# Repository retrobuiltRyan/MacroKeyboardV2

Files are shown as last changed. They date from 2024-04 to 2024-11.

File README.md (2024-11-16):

# MacroKeyboardV2
13-Key Arduino ProMicro USB Macro Keyboard
https://youtu.be/IDlcxLQ1SbY?si=J5Tzyvr0lGsu_4_Y

cache_4109089450

Trouble Shooting Tips and FAQs
Some basic trouble shooting:

 1. This PCB is not plug-and-play. You have to upload at least the example code linked from this product description. Code is on this page.
 2. Use the Arduino IDE to program. (see arduino.cc for help with adding libraries and getting the software to program the Arduino).
 3. Make sure you have these libraries added:
 4. Make sure the Arduino Micro 32u4 is selected when programming this board. Tools> Board> Arduino Micro.
 cache_4108825371

Go to Tools>Manage Libraries.

cache_4108825370

2) Make sure you have the Arduino Pro Micro selected. Tools> Board> Arduino Micro

5. Make sure all the solder jumpers are soldered! You’ll get really weird results (phantom keys) if you miss a jumper.

6. You may have to hold down the reset button, hit upload sketch, wait for the IDE to try to ‘upload’ to the Arduino, then release the reset button.
The boot-loader for uploading is a short window in the Arduino Pro Micro. The Pro Micro wants to default to the USB HID mode. Catching the short window for uploading a program might take a few tries; i.e to get a feel for the timing (my experience).
Search for these libraries. When you find the library listed below, install it.
7. DO NOT SOLDER BOTH I2C power jumpers. Solder only one!
8. cache_4109097346

Eagle CAD files include (9.2.x) I have abondoned EagleCAD for KiCAD. KiCAD can import Eagle design files; happy macro-ing!eagle work

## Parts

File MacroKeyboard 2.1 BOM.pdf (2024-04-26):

Macro Keyboard ver 2.x Bill of Materials | RetroBuiltGames.com (c) Ryan Bates

### Dec 24, 2020

PRO MODEL | FULL RGB Typical Build
Index | Quantity Description | Vendor | Vendor Part Number | Unit Price Extended Price USD | Notes
1 | 1 | Arduino Pro Micro (micro USB conn) ATmega32u4 | - | - | 3.75 | 3.75
2 | 1 | MacroKeyboard v2.x PCB | Ryan | - | 5.00 | 5.00
3 | 11 | Cherry Mx Switch, Blue, RGB SPST-NO | - | - | 0.95 | 10.43 | 3
4 | 11 | CHERRY MX KEYCAP - Clear or Windowed | - | - | 0.95 | 10.45
5 | 2 | Rotary Encoder w/ Switch | DigiKey | 987-1398-ND | 0.78 | 1.56
6 | 2 | Knob for Rotary shaft, 6mm dia | ebay | - | 0.65 | 1.30
7 | 1 | CONN JACK STEREO 3.5MM R/A | DigiKey | CP1-3524NG-ND (or CP1-3523N-ND) | 0.74 | 0.74
8 | 1 | SWITCH TACTILE SPST-NO 0.05A 12V (6x6mm) | DigiKey | 679-2443-ND | 0.30 | 0.30
9 | 0 | CAP KEYSWITCH SQUARE BLACK for 6x6mm switch (OPTIONAL) | DigiKey | 450-1829-ND | 0.12 | -
10 | 2 | 1x12 Header 0.1" pitch | DigiKey | S6100-ND | 0.69 | 1.38
11 | 0 | Diode, small signal. SOD-123 (OPTIONAL) | DigiKey | 1N4148W-13FDICT-ND | 0.18 | - | 1
12 | 1 | RES 330 OHM 5% 1/4W 1206 | DigiKey | RMCF1206JT330RCT-ND | 0.03 | 0.03
13 | 13 | SK6812 MINI-E Addressable RGB LED 5V | AliExpress | https://www.aliexpress.com/item/4000475685852.html?spm=a2g0s.12269583.0.0.572c1e9ceHD99V 0.50 | | 6.50 | 2
14 | 1 | 3D Printed Case - Custom- | Ryan? | - | 0.48 | 0.48
15 | 1 | LCD 4x20 with i2c backpack (or any i2c LCD) | - | - | 4.00 | 4.00
16 | 1 | Potentiometer 5K Ohm (the big kind, like a volume knob) | ebay | - | 1.00 | 1.00
17 | 1 | Screw Terminal, 3 Pos, 5mm pitch | ebay | - | 0.75 | 0.75
| | | total cost | | | 47.67

As Cheap as Possible, No Keyboard switches
Index | Quantity Description | Vendor | Vendor Part Number | Unit Price Extended Price USD | Notes
1 | 1 | Arduino Pro Micro (micro USB conn) ATmega32u4 | - | - | 3.75 | 3.75
2 | 1 | MacroKeyboard v2.x PCB | Ryan | - | 5.00 | 5.00
3 | 11 | SWITCH TACTILE SPST-NO 0.05A 24V (12x12mm) | DigiKey | 450-1158-ND | 0.33 | 3.63 | 4
4 | 11 | CAP TACTILE ROUND BLACK | DigiKey | 679-2315-ND | 0.21 | 2.31
5 | 2 | Rotary Encoder w/ Switch | DigiKey | 987-1398-ND | 0.78 | 1.56
6 | 2 | Knob for Rotary shaft, 6mm dia | ebay | - | 0.65 | 1.30
7 | 0 | CONN JACK STEREO 3.5MM R/A | DigiKey | CP1-3524NG-ND (or CP1-3523N-ND) | 0.74 | -
8 | 1 | SWITCH TACTILE SPST-NO 0.05A 12V (6x6mm) | DigiKey | 679-2443-ND | 0.30 | 0.30
9 | 0 | CAP KEYSWITCH SQUARE BLACK for 6x6mm switch (OPTIONAL) | DigiKey | 450-1829-ND | 0.12 | -
10 | 0 | 1x12 Header 0.1" pitch | DigiKey | S6100-ND | 0.69 | -
11 | 0 | Diode, small signal. SOD-123 (OPTIONAL) | DigiKey | 1N4148W-13FDICT-ND | 0.18 | - | 1
12 | 0 | RES 330 OHM 5% 1/4W 1206 | DigiKey | RMCF1206JT330RCT-ND | 0.03 | -
13 | 0 | SK6812 MINI-E Addressable RGB LED 5V | AliExpress | https://www.aliexpress.com/item/4000475685852.html?spm=a2g0s.12269583.0.0.572c1e9ceHD99V 0.50 | | - | 2
14 | 0 | 3D Printed Case - Custom- | Ryan? | | 0.48 | -
15 | 0 | Potentiometer 5K Ohm (the big kind, like a volume knob) | ebay | - | 1.00 | -
16 | 0 | Screw Terminal, 3 Pos, 5mm pitch | ebay | - | 0.75 | -
17 | 0 | LCD 4x20 with i2c backpack (or any i2c LCD) | - | - | 4.00 | -
| | | total cost | | | 17.85

Notes:
1 Optional; solder bypass jumper pads if not using anti-ghosting diodes.
2 Haven't found a reliable supplier for this part. Check datasheet before buying!
3 Any compatible keyboard switch will work. Can sub for non- transparent body if not backlighting with LEDs 4 Use generic tac switch, not Omrom (locating holes arent drilled for the Omrom nubs)

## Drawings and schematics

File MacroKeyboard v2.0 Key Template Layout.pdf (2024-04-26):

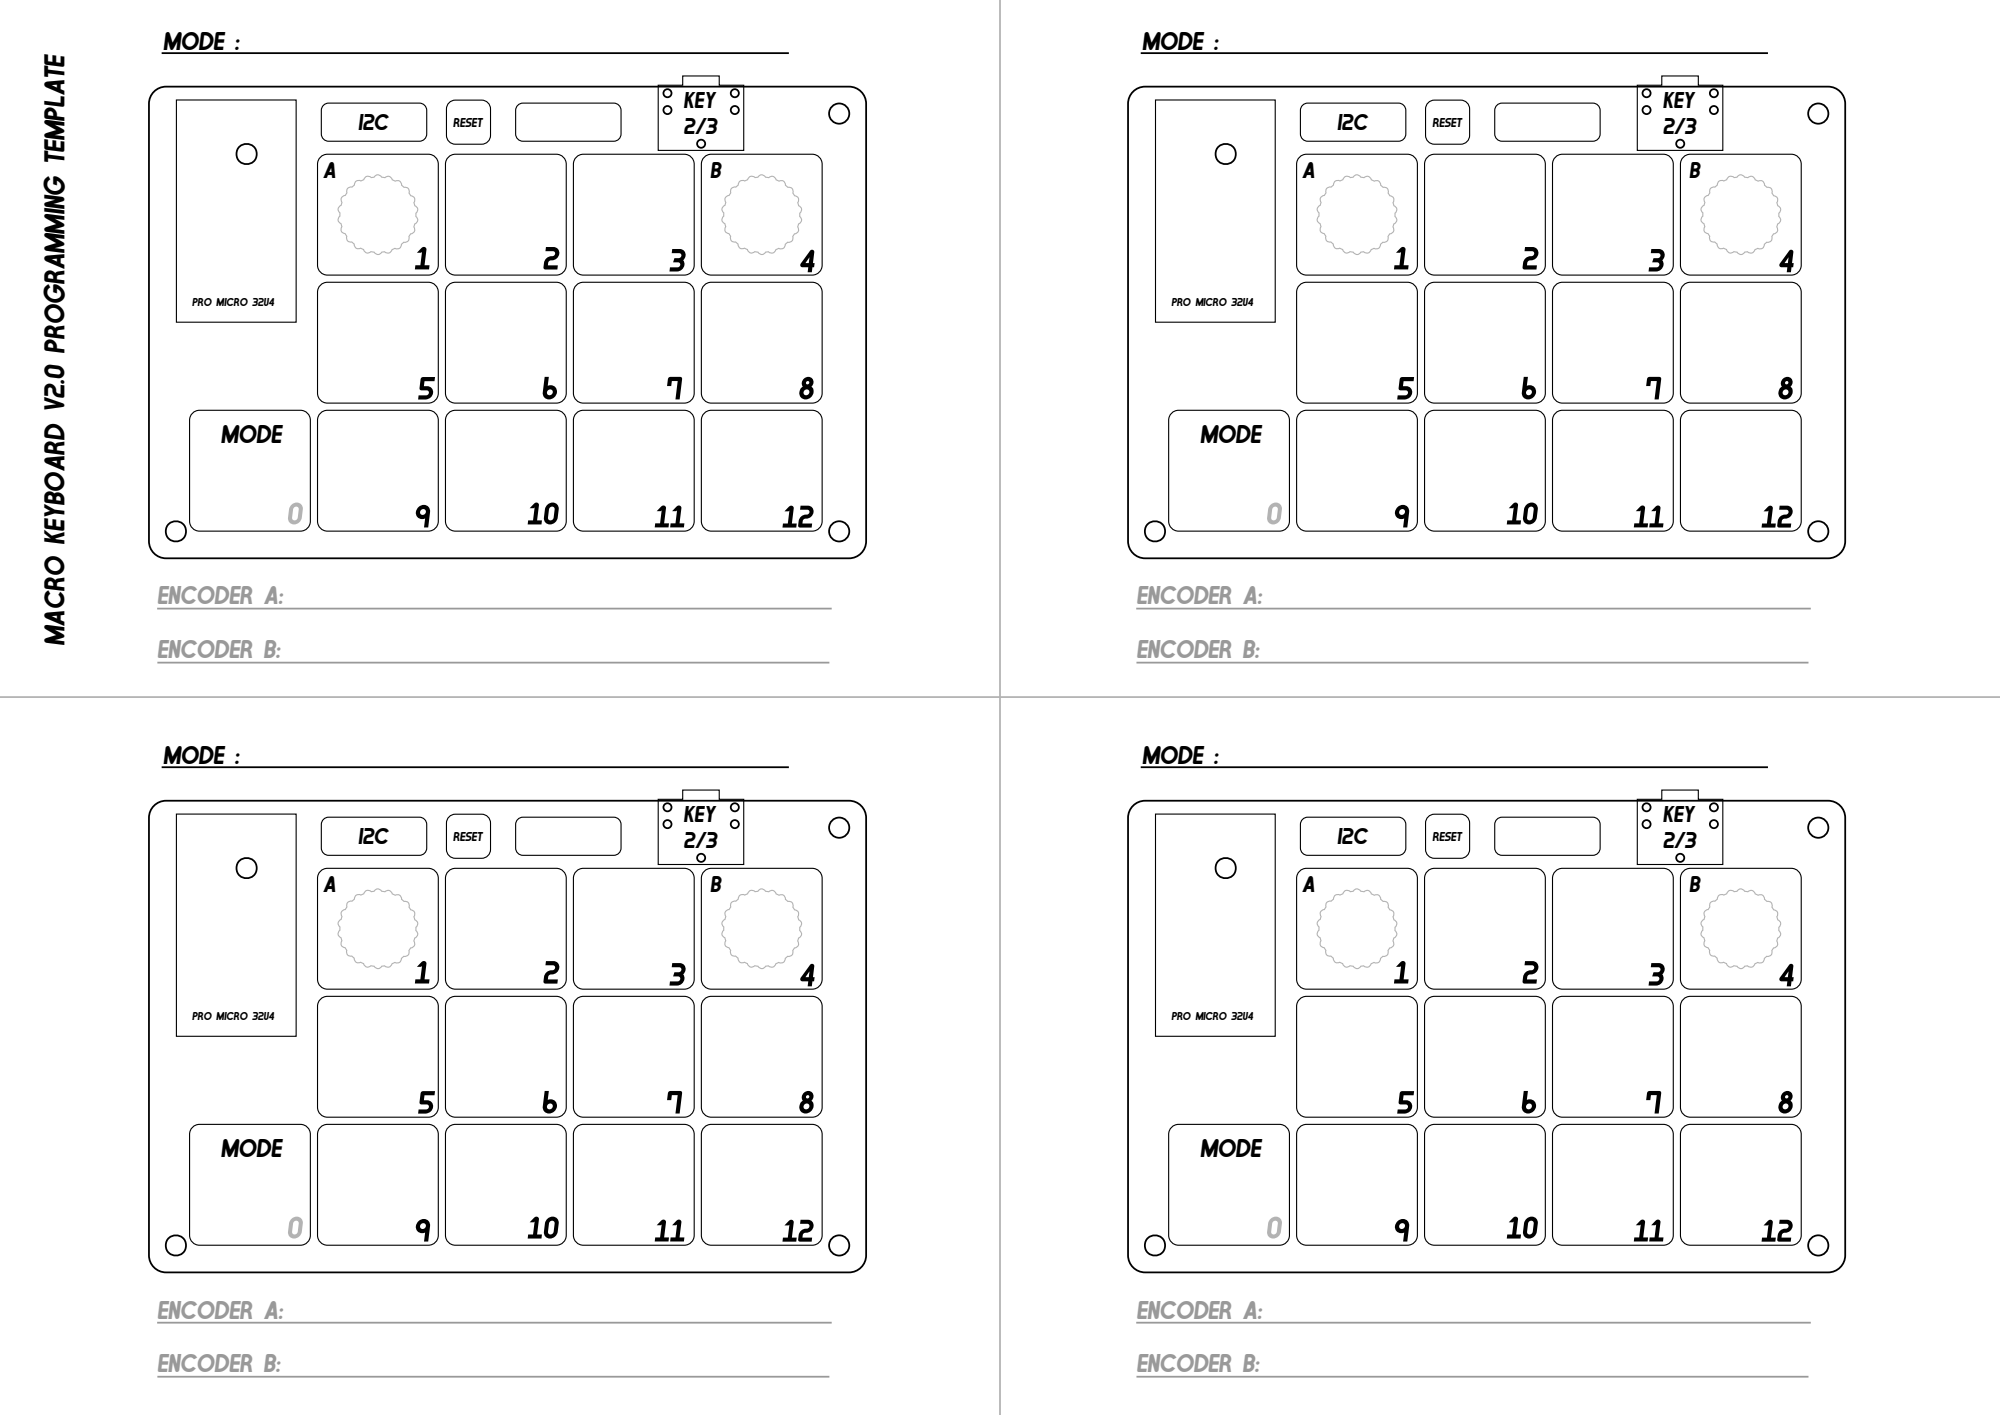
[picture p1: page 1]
PRO MICRO 32U4; RESET; MODE; KEY 2/3; MODE :; ENCODER A:; ENCODER B:

MACRO KEYBOARD V2.0 PROGRAMMING TEMPLATE

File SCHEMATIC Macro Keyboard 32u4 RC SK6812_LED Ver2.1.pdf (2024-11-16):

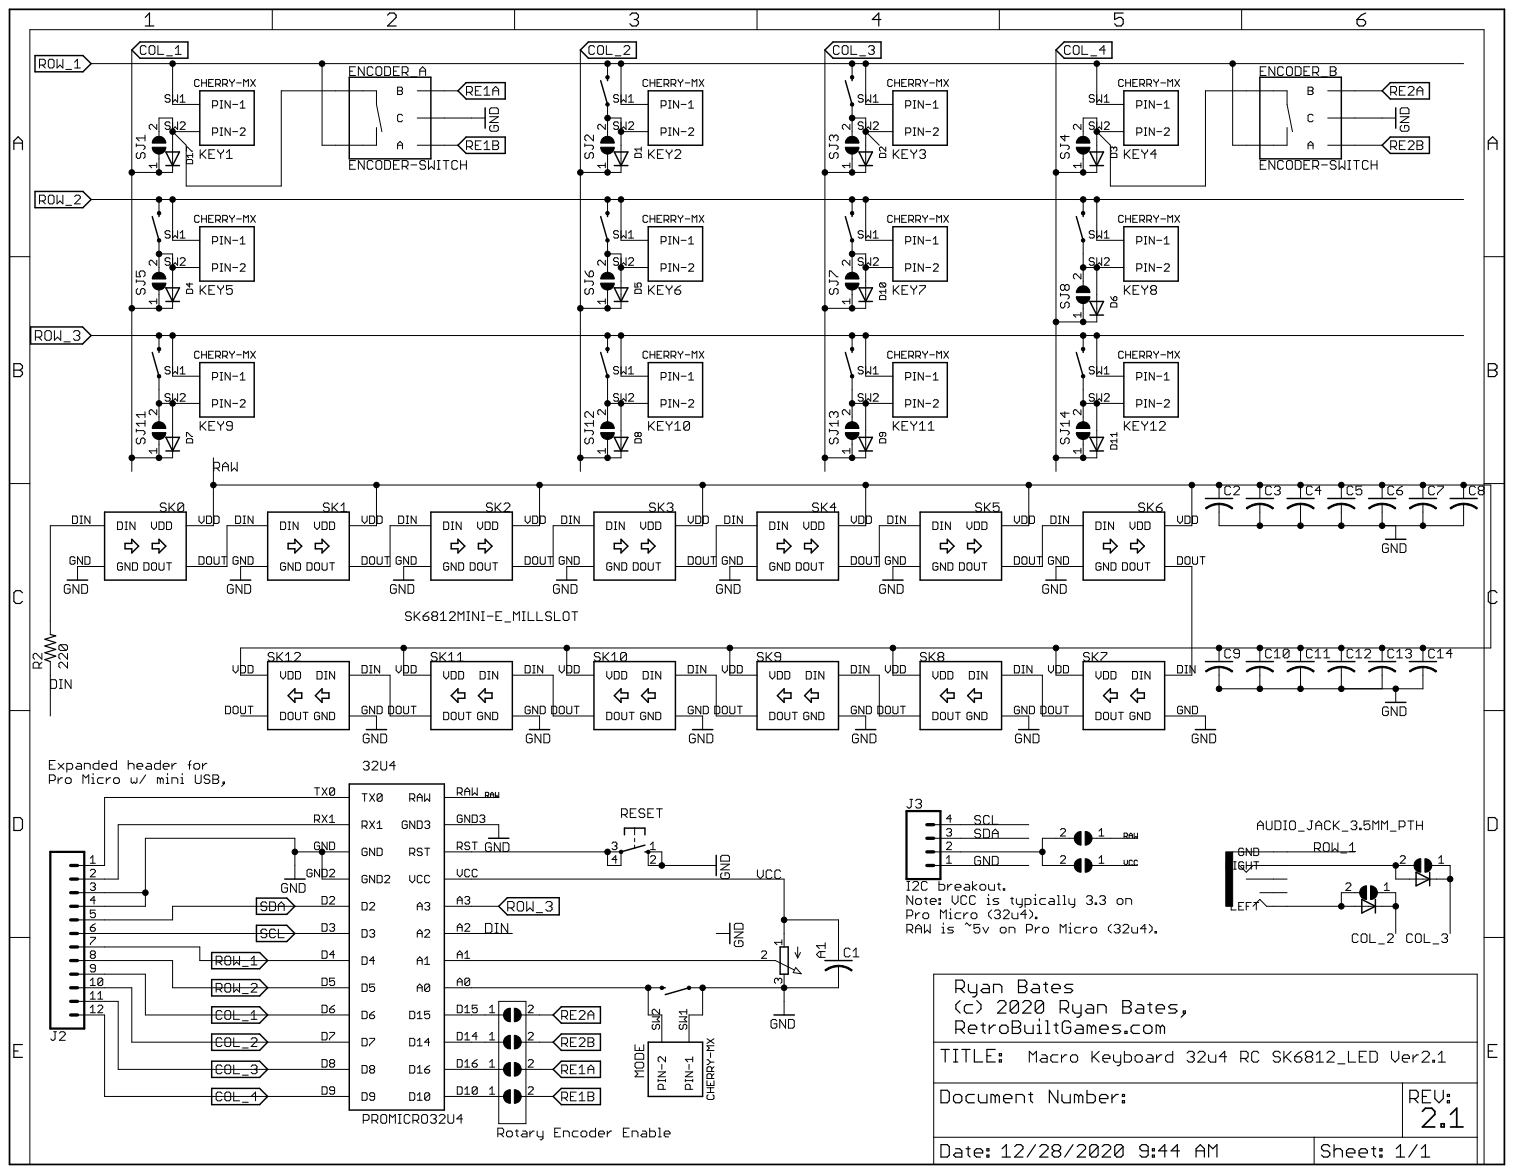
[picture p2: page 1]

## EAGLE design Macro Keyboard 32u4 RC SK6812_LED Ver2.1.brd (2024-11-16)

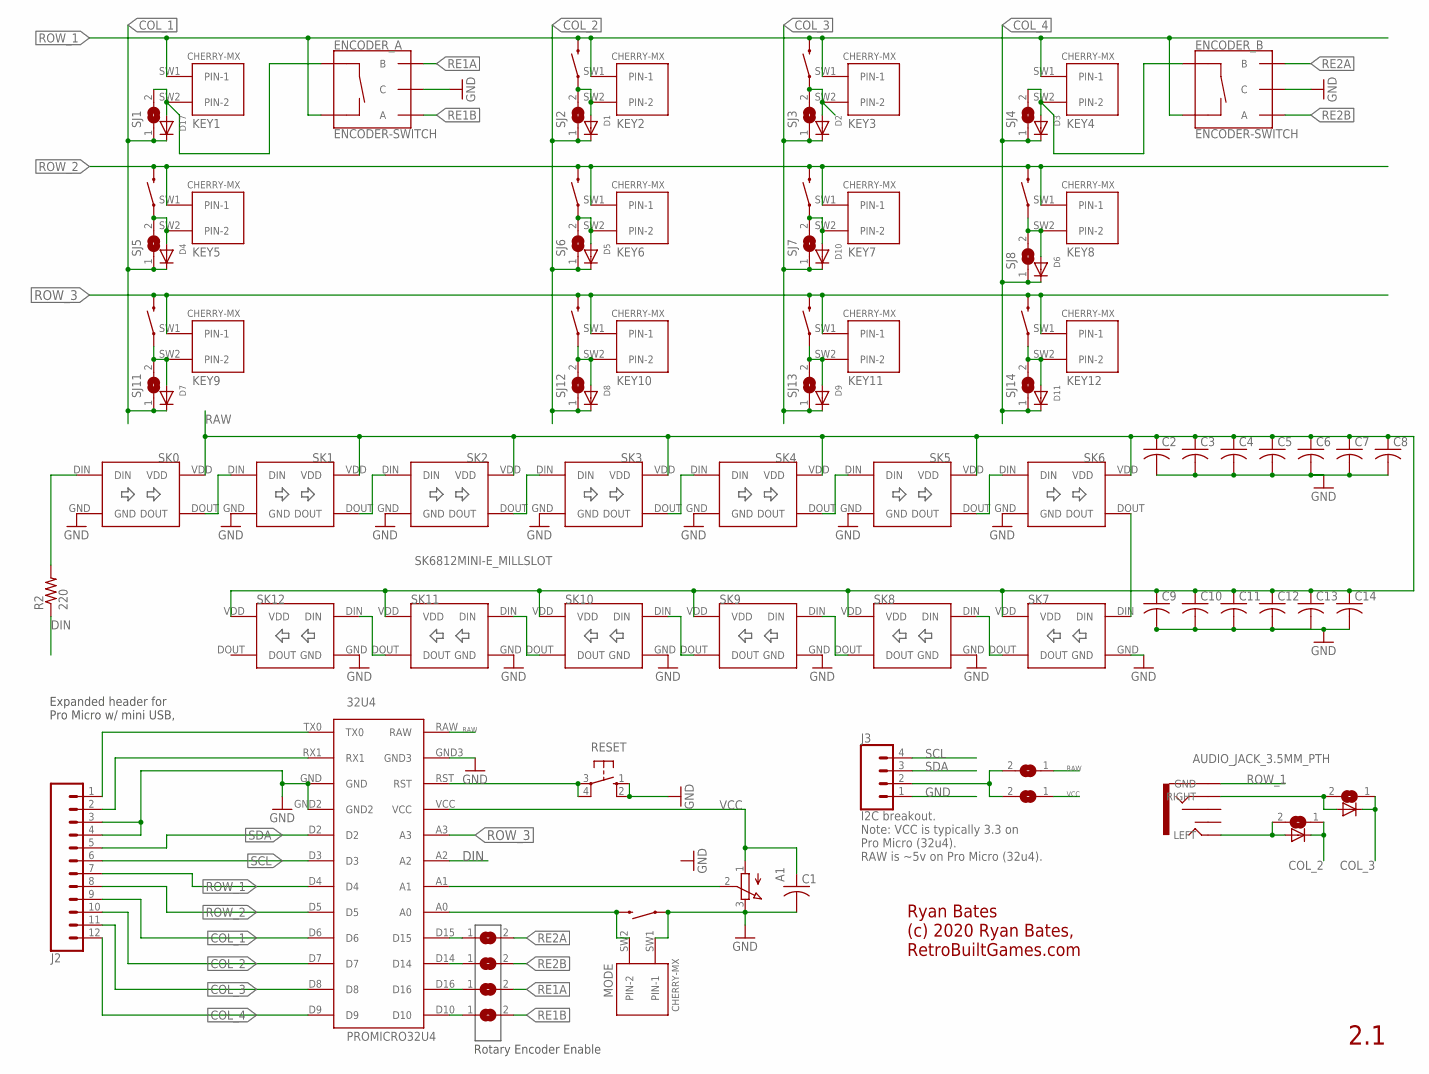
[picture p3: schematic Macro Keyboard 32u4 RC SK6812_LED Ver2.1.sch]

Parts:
32U4: PROMICRO32U4
A1: 3RP/1610N
C1: C-USC1206; C1206
C2, C3, C4, C5, C6, C7, C8, C9, C10, C11, C12, C13, C14: C-USC0805K; C0805K
D1, D2, D3, D4, D5, D6, D7, D8, D9, D10, D11, D15, D16, D17: DIODESOD-123; SOD-123
ENCODER_A: ENCODER-SWITCH; ROTARY_ENC_PLAIN
ENCODER_B: ENCODER-SWITCH; ROTARY_ENC_PLAIN
J1: AUDIO_JACK_3.5MM_PTH; AUDIO-JACK
J2: CONN_12NO_SILK; 1X12_NO_SILK
J3: CONN_041X04_NO_SILK; 1X04_NO_SILK
KEY1, KEY2, KEY3, KEY4, KEY5, KEY6, KEY7, KEY8, KEY9, KEY10, KEY11, KEY12: CHERRY-MX
MODE: CHERRY-MX
R2: 220; M1206
RESET: 10-XX; B3F-10XX
S1, S2, S3, S4, S5, S6, S7, S8, S9, S10, S11: MOMENTARY-SWITCH-SPST-PTH-12MM; TACTILE_SWITCH_PTH_12MM
SJ1, SJ2, SJ3, SJ4, SJ5, SJ6, SJ7, SJ8, SJ9, SJ10, SJ11, SJ12, SJ13, SJ14, SJ16, SJ17, SJ18, SJ19, SJ20, SJ21: SJ
SK0, SK1, SK2, SK3, SK4, SK5, SK6, SK7, SK8, SK9, SK10, SK11, SK12: SK6812MINI-E_MILLSLOT

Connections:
COL_1: 32U4.D6, D4.C, D7.C, D17.C, J2.9, SJ1.1, SJ5.1, SJ11.1
COL_2: 32U4.D7, D1.C, D5.C, D8.C, D15.C, J2.10, SJ2.1, SJ6.1, SJ12.1, SJ16.1
COL_3: 32U4.D8, D2.C, D9.C, D10.C, D16.C, J2.11, SJ3.1, SJ7.1, SJ13.1, SJ17.1
COL_4: 32U4.D9, D3.C, D6.C, D11.C, J2.12, SJ4.1, SJ8.1, SJ14.1
DIN: 32U4.A2, R2.1
GND: 32U4.GND, 32U4.GND2, 32U4.GND3, A1.3 (E), C1.2, C2.2, C3.2, C4.2, C5.2, C6.2, C7.2, C8.2, C9.2, C10.2, C11.2, C12.2, C13.2, C14.2, ENCODER_A.C, ENCODER_B.C, J2.3, J2.4, J3.1, MODE.SW1 (PIN-1), RESET.1 (S), RESET.2 (S1), S11.1, SK0.GND, SK1.GND, SK2.GND, SK3.GND, SK4.GND, SK5.GND, SK6.GND, SK7.GND, SK8.GND, SK9.GND, SK10.GND, SK11.GND, SK12.GND
unnamed: 32U4.RX1, J2.2
unnamed: D1.A, KEY2.SW2 (PIN-2), S4.1, SJ2.2
unnamed: D4.A, KEY5.SW2 (PIN-2), S9.1, SJ5.2
unnamed: D5.A, KEY6.SW2 (PIN-2), S10.1, SJ6.2
unnamed: SK0.DOUT, SK1.DIN
unnamed: D3.A, ENCODER_B.SW+, KEY4.SW2 (PIN-2), SJ4.2
unnamed: D2.A, KEY3.SW2 (PIN-2), S3.1, SJ3.2
unnamed: D16.A, J1.RIGHT, SJ17.2
unnamed: 32U4.RST, RESET.3, RESET.4 (P1)
unnamed: 32U4.TX0, J2.1
unnamed: 32U4.A0, MODE.SW2 (PIN-2), S11.3 (2)
unnamed: SK1.DOUT, SK2.DIN
unnamed: SK2.DOUT, SK3.DIN
unnamed: D10.A, KEY7.SW2 (PIN-2), S1.1, SJ7.2
unnamed: R2.2, SK0.DIN
unnamed: D6.A, KEY8.SW2 (PIN-2), S2.1, SJ8.2
unnamed: D17.A, ENCODER_A.SW+, KEY1.SW2 (PIN-2), SJ1.2
unnamed: SK3.DOUT, SK4.DIN
unnamed: J3.2, SJ9.2, SJ10.2
unnamed: D7.A, KEY9.SW2 (PIN-2), S5.1, SJ11.2
unnamed: 32U4.A1, A1.2 (S)
unnamed: D9.A, KEY11.SW2 (PIN-2), S7.1, SJ13.2
unnamed: D8.A, KEY10.SW2 (PIN-2), S6.1, SJ12.2
unnamed: D11.A, KEY12.SW2 (PIN-2), S8.1, SJ14.2
unnamed: SK4.DOUT, SK5.DIN
unnamed: SK5.DOUT, SK6.DIN
unnamed: SK6.DOUT, SK7.DIN
unnamed: SK7.DOUT, SK8.DIN
unnamed: SK8.DOUT, SK9.DIN
unnamed: SK9.DOUT, SK10.DIN
unnamed: 32U4.D15, SJ18.1
unnamed: 32U4.D14, SJ19.1
unnamed: 32U4.D16, SJ20.1
unnamed: 32U4.D10, SJ21.1
unnamed: SK10.DOUT, SK11.DIN
unnamed: SK11.DOUT, SK12.DIN
unnamed: D15.A, J1.LEFT, SJ16.2
RAW: 32U4.RAW, C2.1, C3.1, C4.1, C5.1, C6.1, C7.1, C8.1, C9.1, C10.1, C11.1, C12.1, C13.1, C14.1, SJ9.1, SK0.VDD, SK1.VDD, SK2.VDD, SK3.VDD, SK4.VDD, SK5.VDD, SK6.VDD, SK7.VDD, SK8.VDD, SK9.VDD, SK10.VDD, SK11.VDD, SK12.VDD
RE1A: ENCODER_A.B, SJ20.2
RE1B: ENCODER_A.A, SJ21.2
RE2A: ENCODER_B.B, SJ18.2
RE2B: ENCODER_B.A, SJ19.2
ROW_1: 32U4.D4, ENCODER_A.SW-, ENCODER_B.SW-, J1.GND, J2.7, KEY1.SW1 (PIN-1), KEY2.SW1 (PIN-1), KEY3.SW1 (PIN-1), KEY4.SW1 (PIN-1), S3.3 (2), S4.3 (2)
ROW_2: 32U4.D5, J2.8, KEY5.SW1 (PIN-1), KEY6.SW1 (PIN-1), KEY7.SW1 (PIN-1), KEY8.SW1 (PIN-1), S1.3 (2), S2.3 (2), S9.3 (2), S10.3 (2)
ROW_3: 32U4.A3, KEY9.SW1 (PIN-1), KEY10.SW1 (PIN-1), KEY11.SW1 (PIN-1), KEY12.SW1 (PIN-1), S5.3 (2), S6.3 (2), S7.3 (2), S8.3 (2)
SCL: 32U4.D3, J2.6, J3.4
SDA: 32U4.D2, J2.5, J3.3
VCC: 32U4.VCC, A1.1 (A), C1.1, SJ10.1

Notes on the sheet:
Rotary Encoder Enable
2.1
Ryan Bates (c) 2020 Ryan Bates, RetroBuiltGames.com
Expanded header for Pro Micro w/ mini USB,
I2C breakout. Note: VCC is typically 3.3 on Pro Micro (32u4). RAW is ~5v on Pro Micro (32u4).

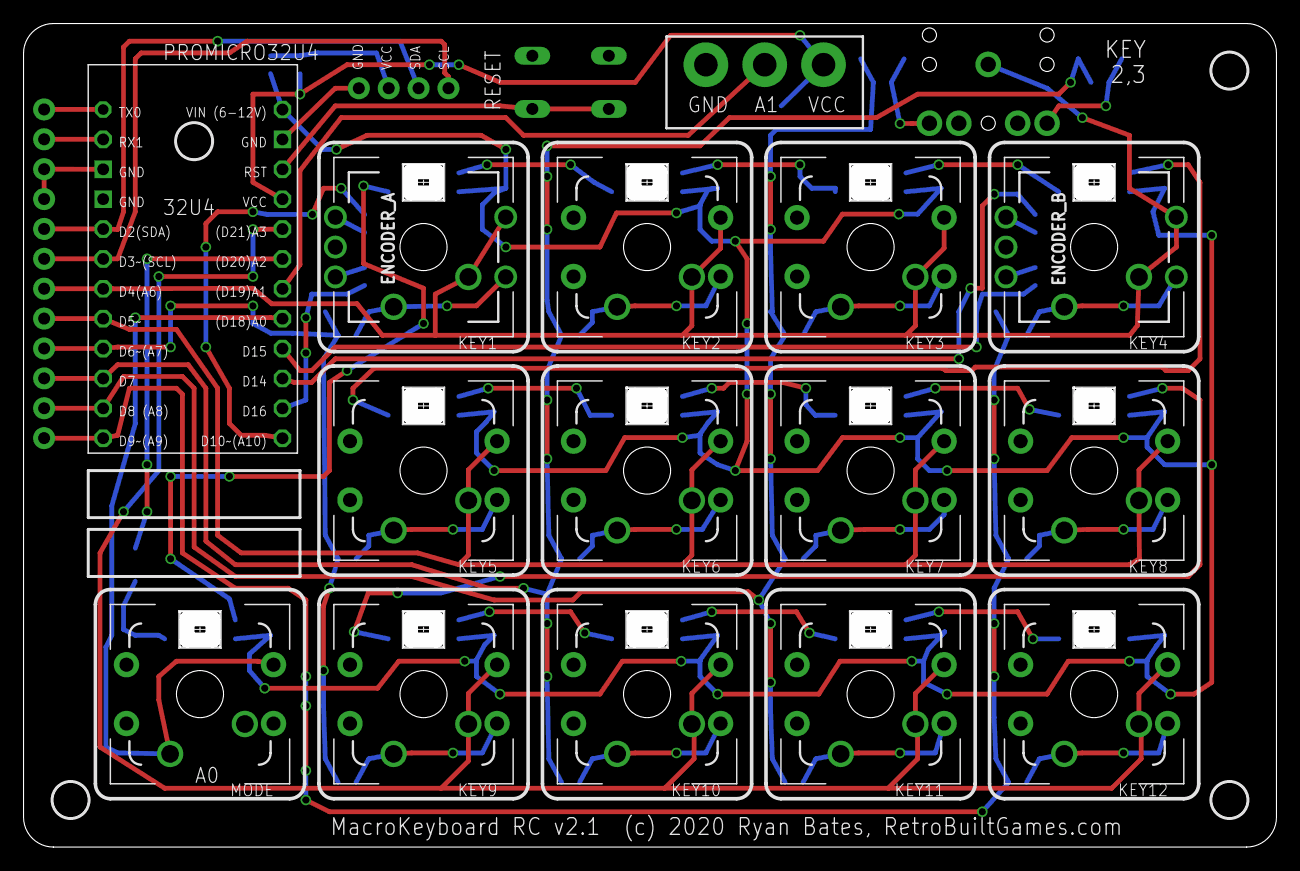
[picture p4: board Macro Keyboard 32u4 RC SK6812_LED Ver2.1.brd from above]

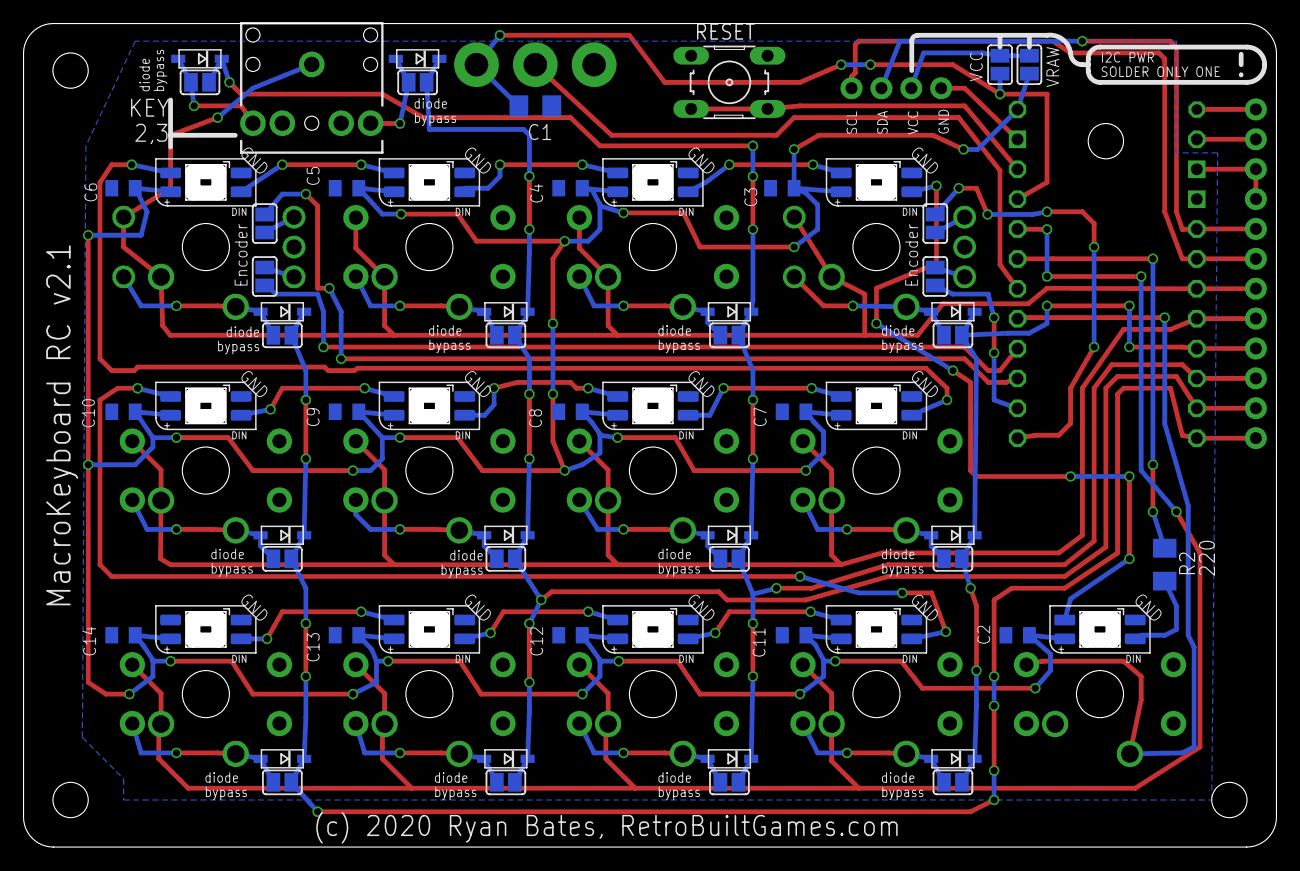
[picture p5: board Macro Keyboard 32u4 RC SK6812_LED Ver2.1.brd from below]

Board: 2 copper layers, 106.5 x 70.0 mm, 98 parts (51 on the bottom side), 54 nets.

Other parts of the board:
U$1, U$2, U$7, U$8: 3,0

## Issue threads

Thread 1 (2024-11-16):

Only PCB V1 is included

Bruur-vr, 2024-11-16:
First time actually using Github:

After opening .brd & .sch files they are for v1 (2 row 4 column). Would it be possible to upload V2?

retrobuiltRyan, 2024-11-16:
oops.
Im in the git right now, removing the outdated, uploading the correct.
thank you! be ready in 10min i think

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

retrobuiltRyan, 2024-11-16:
fixed.

retrobuiltRyan, 2024-11-16:
also removing v.10

Closed 2024-11-16.

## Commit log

2024-04-26 Create Simple Macros, LCD and RGB LED support
    A multi-mode Macro keyboard with Arduino Pro Micro using row column matrix.
    * This is a basic sketch to understand key layout, basic hotkeys macros and some extras like:
    * -RBG addressable LEDs compatible with Adafruit's neopixel library.
    * -i2c for 4x20 LCD to describe each function. (you might have a different LCD...)
    * -mouse movement + mouse clicks.
2024-09-09 PCB design files and GERBERs
    (EAGLE v9.x CAD schematic and board.
    GERBERS (the .zip file) were typically ordered from JLCPCB
    [Macro Keyboard 32u4 Row Column MiniMacro v1.0.brd, Macro Keyboard 32u4 Row Column MiniMacro v1.0.sch]
2024-11-16 correct macro keyboard v2.1 files uploaded
    [Macro Keyboard 32u4 RC SK6812_LED Ver2.1.brd, Macro Keyboard 32u4 RC SK6812_LED Ver2.1.sch]
2024-11-16 Delete Macro Keyboard 32u4 Row Column MiniMacro v1.0.sch
    wrong file
    [Macro Keyboard 32u4 Row Column MiniMacro v1.0.sch]
2024-11-16 Delete Macro Keyboard 32u4 Row Column MiniMacro v1.0.brd
    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
    [Macro Keyboard 32u4 Row Column MiniMacro v1.0.brd]
2024-11-16 Update README.md
    note about kiCAD

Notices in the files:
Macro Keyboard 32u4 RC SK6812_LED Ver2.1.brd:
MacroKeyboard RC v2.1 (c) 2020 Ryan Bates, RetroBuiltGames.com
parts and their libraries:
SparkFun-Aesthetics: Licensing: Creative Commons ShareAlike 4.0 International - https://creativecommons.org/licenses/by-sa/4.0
